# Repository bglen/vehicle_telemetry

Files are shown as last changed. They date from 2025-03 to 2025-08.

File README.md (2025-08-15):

# Vehicle Telemetry System

*Note: This is a work in progress and many features are not implemented yet.*

The Vehicle Telemetry System is an offline-first, containerized CAN data logging system. The system is designed to provide live telemetry and data logging for race cars, but can easilly be adapted to any mobile vehicle or robotic platform that uses CAN networks.

# Architecture Overview
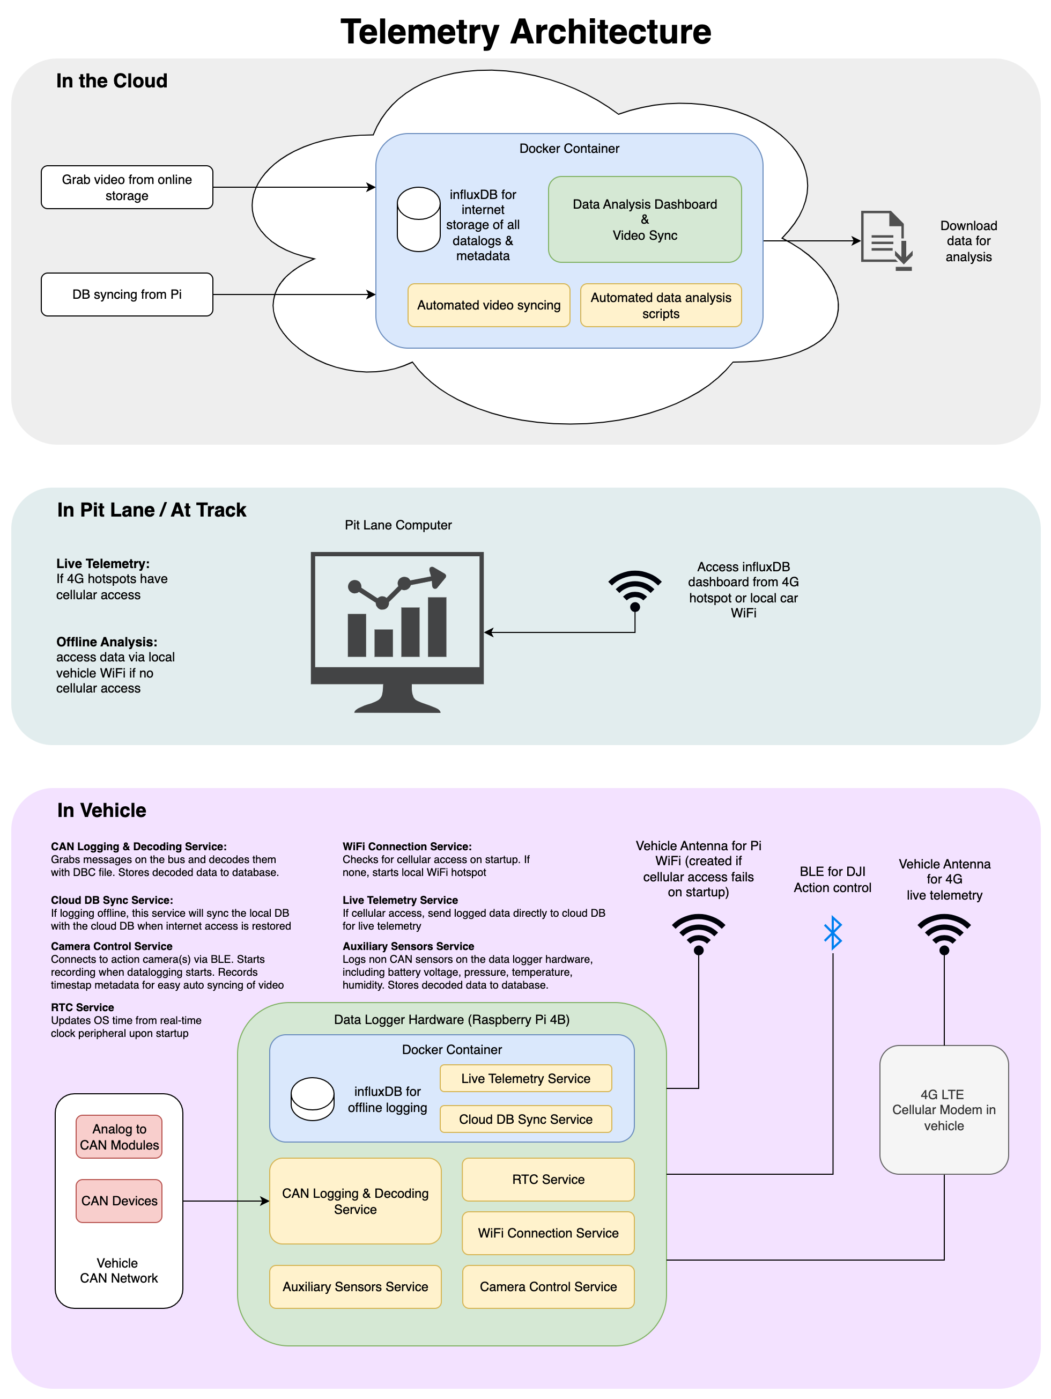
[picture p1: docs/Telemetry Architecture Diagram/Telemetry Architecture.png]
Telemetry Architecture


### Current Features
- Logs CAN and decodes to CSV file
- Ability to decode using multiple DBC files
- Access and download decoded log files on the logger's local WiFi hotspot
- Handles sudden power loss gracefully
- Supports two CAN 2.0B networks up to 1 Mbps
- Logs data from NMEA format USB GPS devices

### Future Functionality
- Stores data to local influxDB database when logging offline. Syncs data to cloud database when internet access is detected.
- Bluetooth control of action cameras (GoPro, DJI Action)

# Data Logger

## Hardware Overview

This repo contains the hardware design for an open-source Raspberry Pi-based CAN data logger.

- Raspberry Pi 4 Model B
- 12V nominal power
- Can log two CAN networks
- GPIO for remote button for log start/stop and logging status LEDs
- Real time clock for accurate data time-stamps when not connected to internet
- Temperature, pressure, and humidity SPI sensor
- Bus voltage logging

## Datalogger Software Setup

1. Create a fresh install of Raspberry Pi OS on your Pi 4B
2. Connect to your Pi via SSH or other methods. Ensure it has an internet connection.
3. Update apt and install git and jq: `sudo apt upgrade -y && sudo apt install -y git jq`
4. Clone the repo: `git clone https://github.com/bglen/vehicle_telemetry`
5. Go to the setup folder: `cd vehicle_telemetry/software/datalogger/setup`
6. Make **install.sh** executable: `chmod +x install.sh`
7. Run the installer: `./install.sh`
8. During the install, enter in your preferred access point network name and trusted network details.
9. Reboot the Pi: `sudo reboot`

# Data Visualiation Tool

A python data visualization tool is provided and uses **rerun.io** to visualize .CSV log files.

## License
MIT License

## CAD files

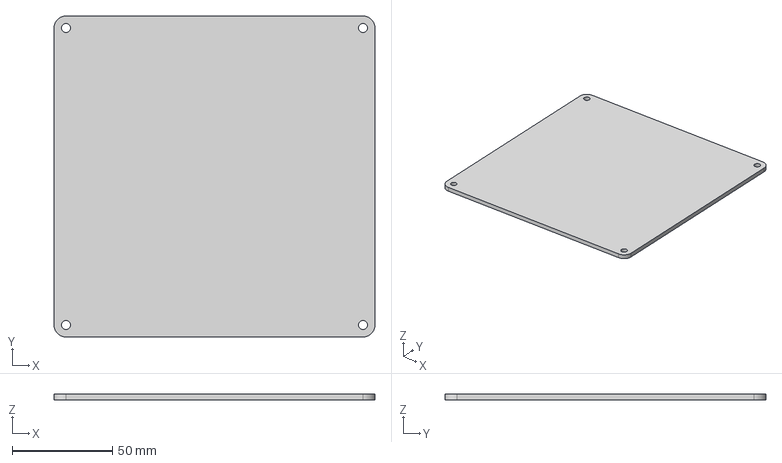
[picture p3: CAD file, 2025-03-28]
hardware/cad/step/datalogger_lid.step
160.0 x 160.0 x 3.00 mm

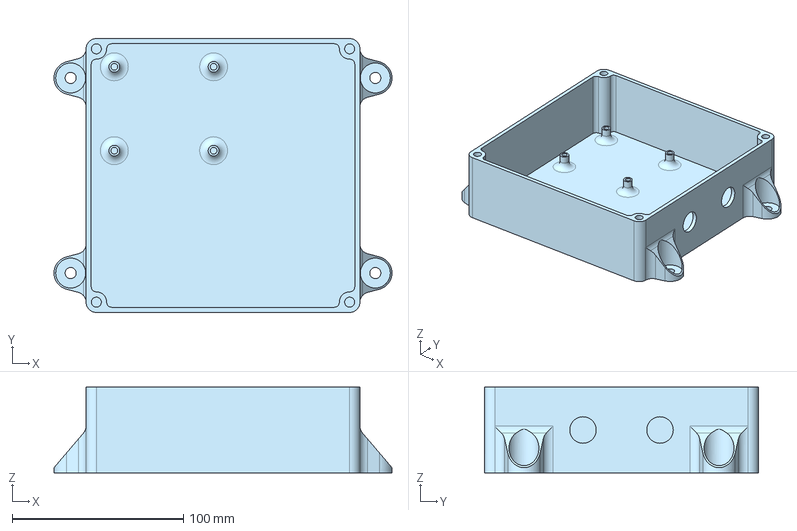
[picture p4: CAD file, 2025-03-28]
hardware/cad/step/datalogger_enclosure.step
197.5 x 160.0 x 50.0 mm

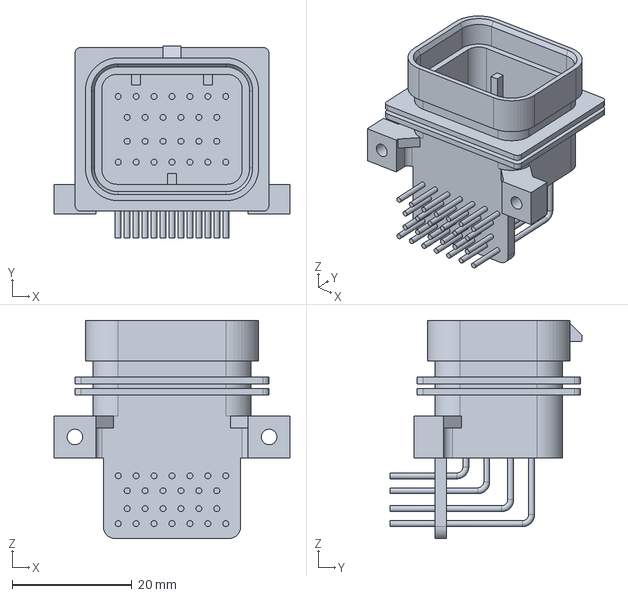
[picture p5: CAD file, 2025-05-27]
hardware/can_datalogger_board/3d_models/amp_superseal_9-6437287-8.step
39.5 x 32.1 x 36.5 mm

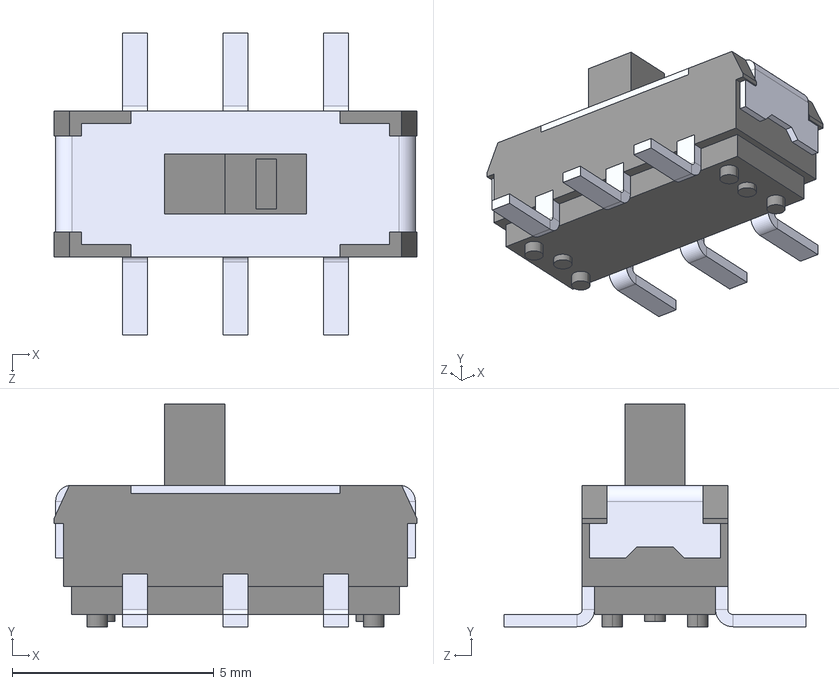
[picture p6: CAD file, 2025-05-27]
hardware/can_datalogger_board/3d_models/JS202011SCQN.STEP
8.99 x 5.51 x 7.49 mm

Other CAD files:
hardware/cad/stl/datalogger_enclosure.stl
hardware/cad/stl/datalogger_lid.stl

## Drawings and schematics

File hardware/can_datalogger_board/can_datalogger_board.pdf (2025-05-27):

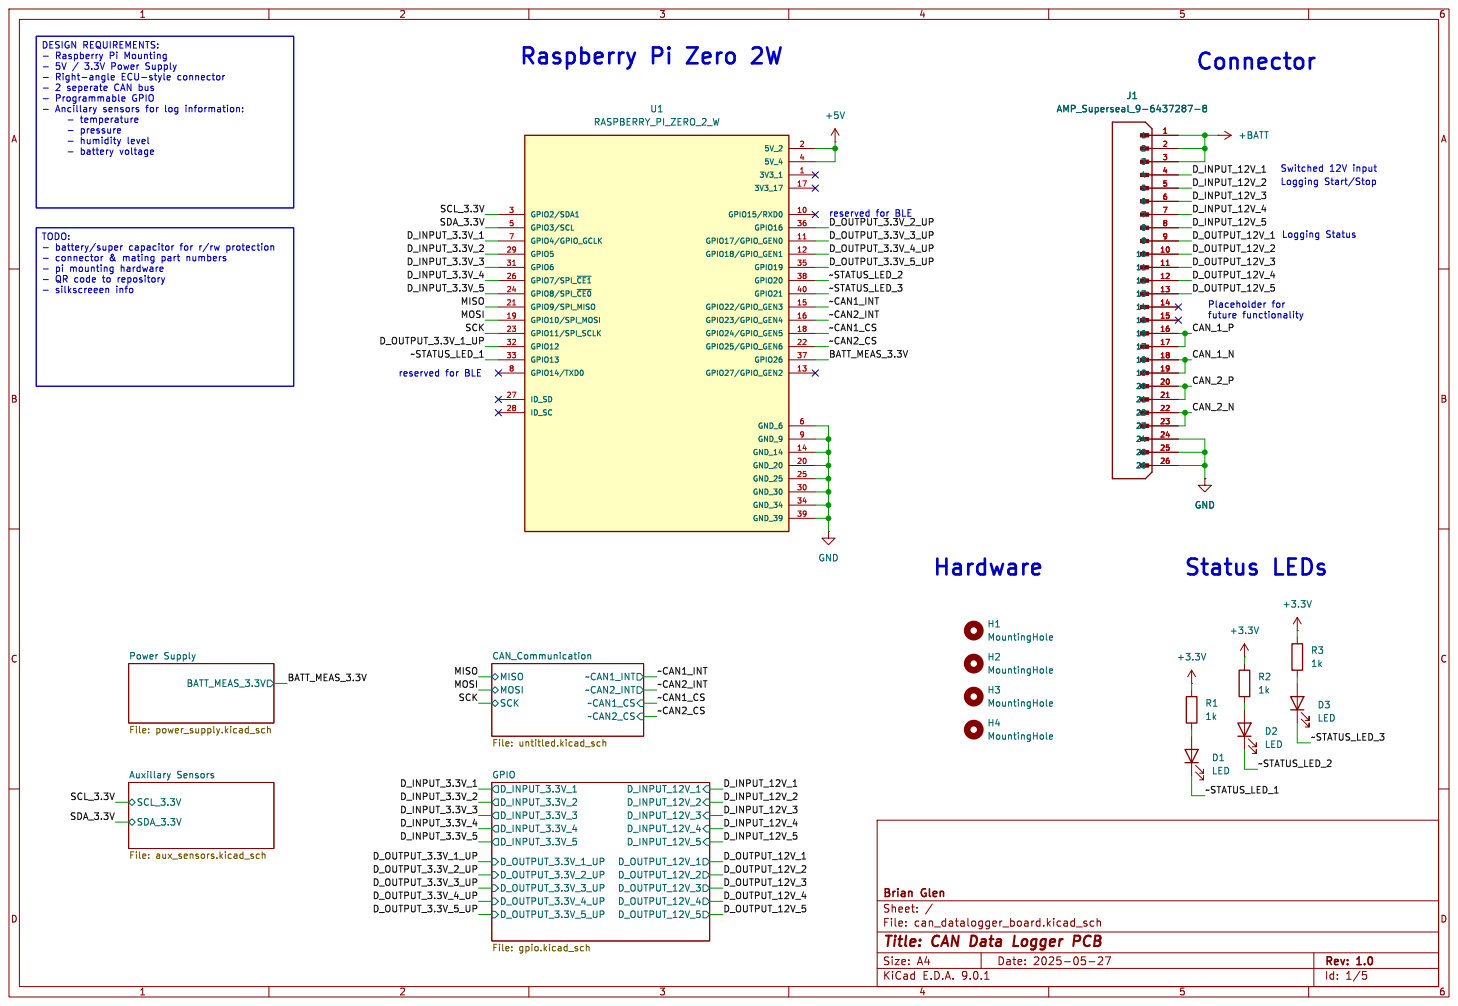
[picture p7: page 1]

Switched 12V input reserved for BLE

- QR code to repository

File: can_datalogger_board.kicad_sch Sheet: / Brian Glen

Id: 1/5 Title: CAN Data Logger PCB

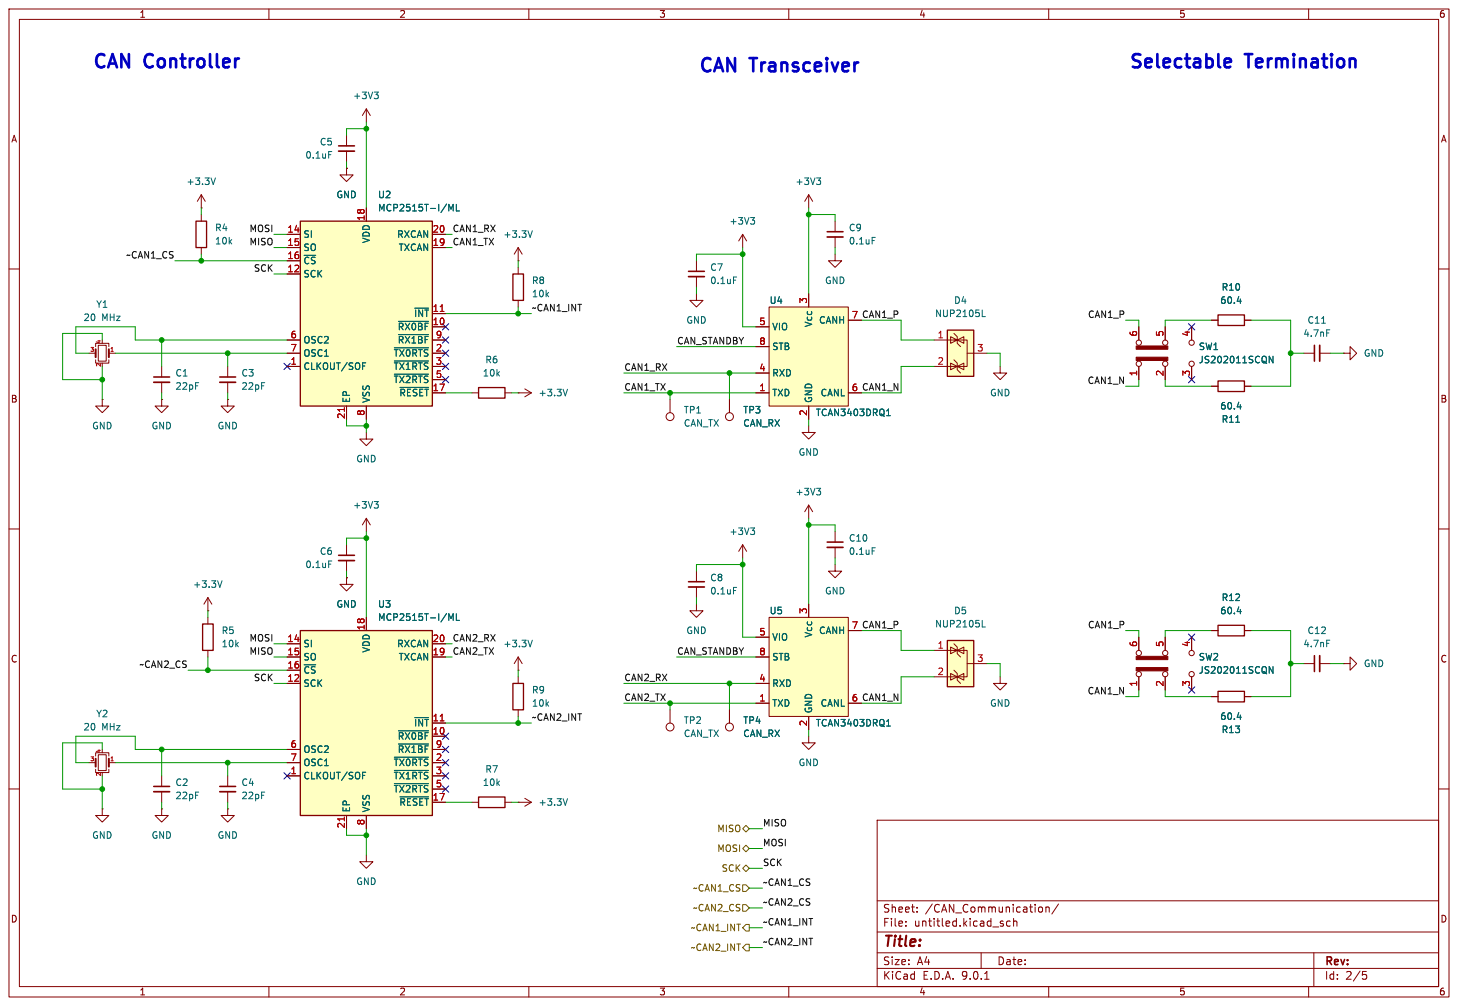
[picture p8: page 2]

8 RXCAN 20 TXCAN 19 ~{INT} 11 ~{RX0BF}10 ~{RX1BF}9 ~{TX0RTS}2 ~{TX1RTS}3 ~{TX2RTS}5 ~{RESET} 17 GND

8 RXCAN 20 TXCAN 19 ~{INT} 11 ~{RX0BF}10 ~{RX1BF}9 ~{TX0RTS}2 ~{TX1RTS}3 ~{TX2RTS}5 ~{RESET} 17 U2 MCP2515T-I/ML +3V3 R9

JS202011SCQN GND MISO MOSI SCK

8 RXCAN 20 TXCAN 19 ~{INT} 11 ~{RX0BF}10 ~{RX1BF}9 ~{TX0RTS}2 ~{TX1RTS}3 ~{TX2RTS}5 ~{RESET} 17 U3 MCP2515T-I/ML GND

Id: 2/5 Title: File: untitled.kicad_sch Sheet: /CAN_Communication/ GND GND

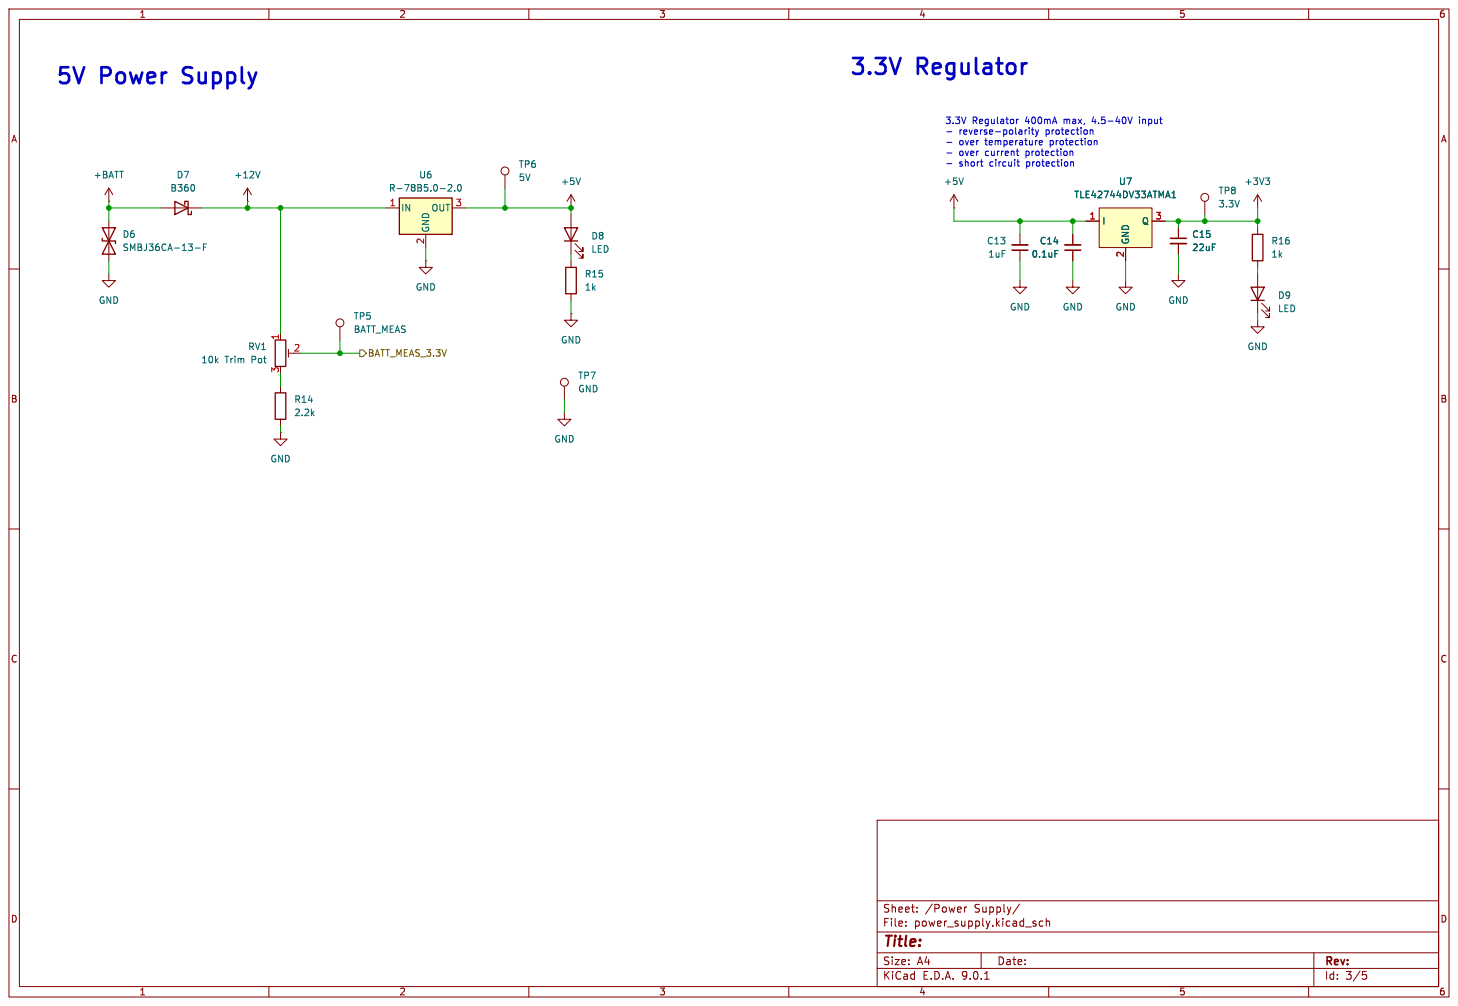
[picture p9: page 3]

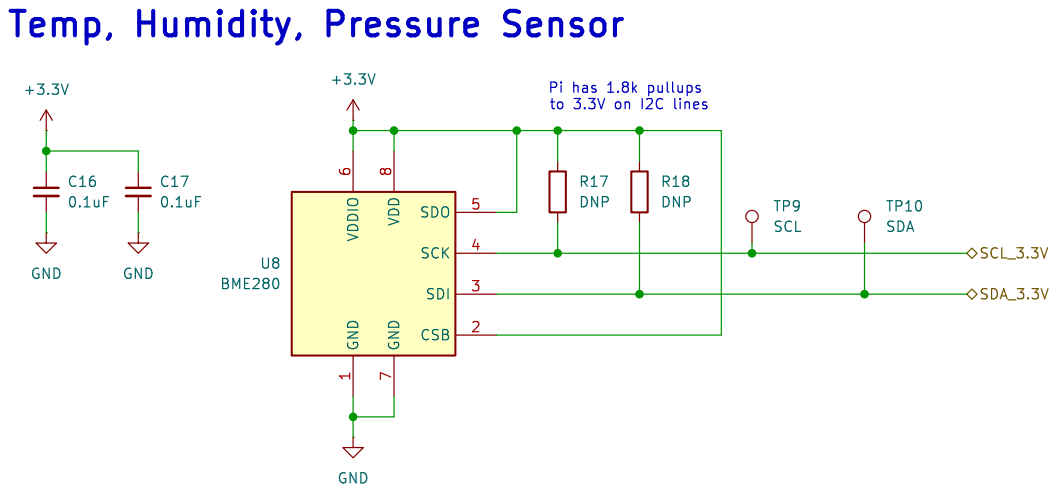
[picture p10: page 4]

7 SDO 5 SCK 4 SDI 3 CSB 2 U8 BME280 GND

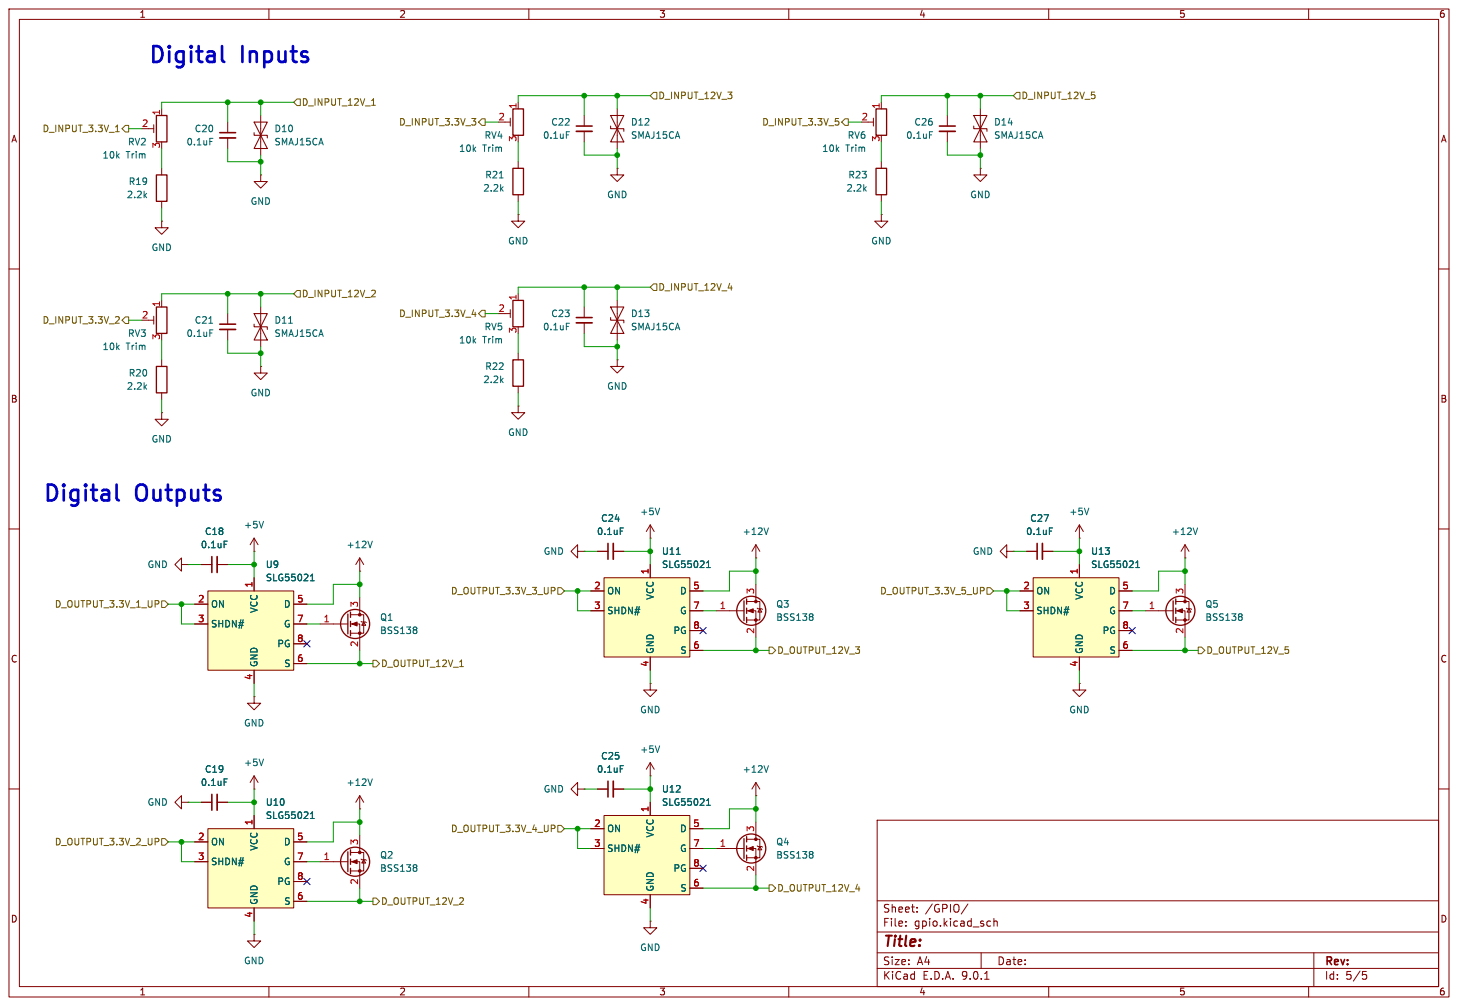
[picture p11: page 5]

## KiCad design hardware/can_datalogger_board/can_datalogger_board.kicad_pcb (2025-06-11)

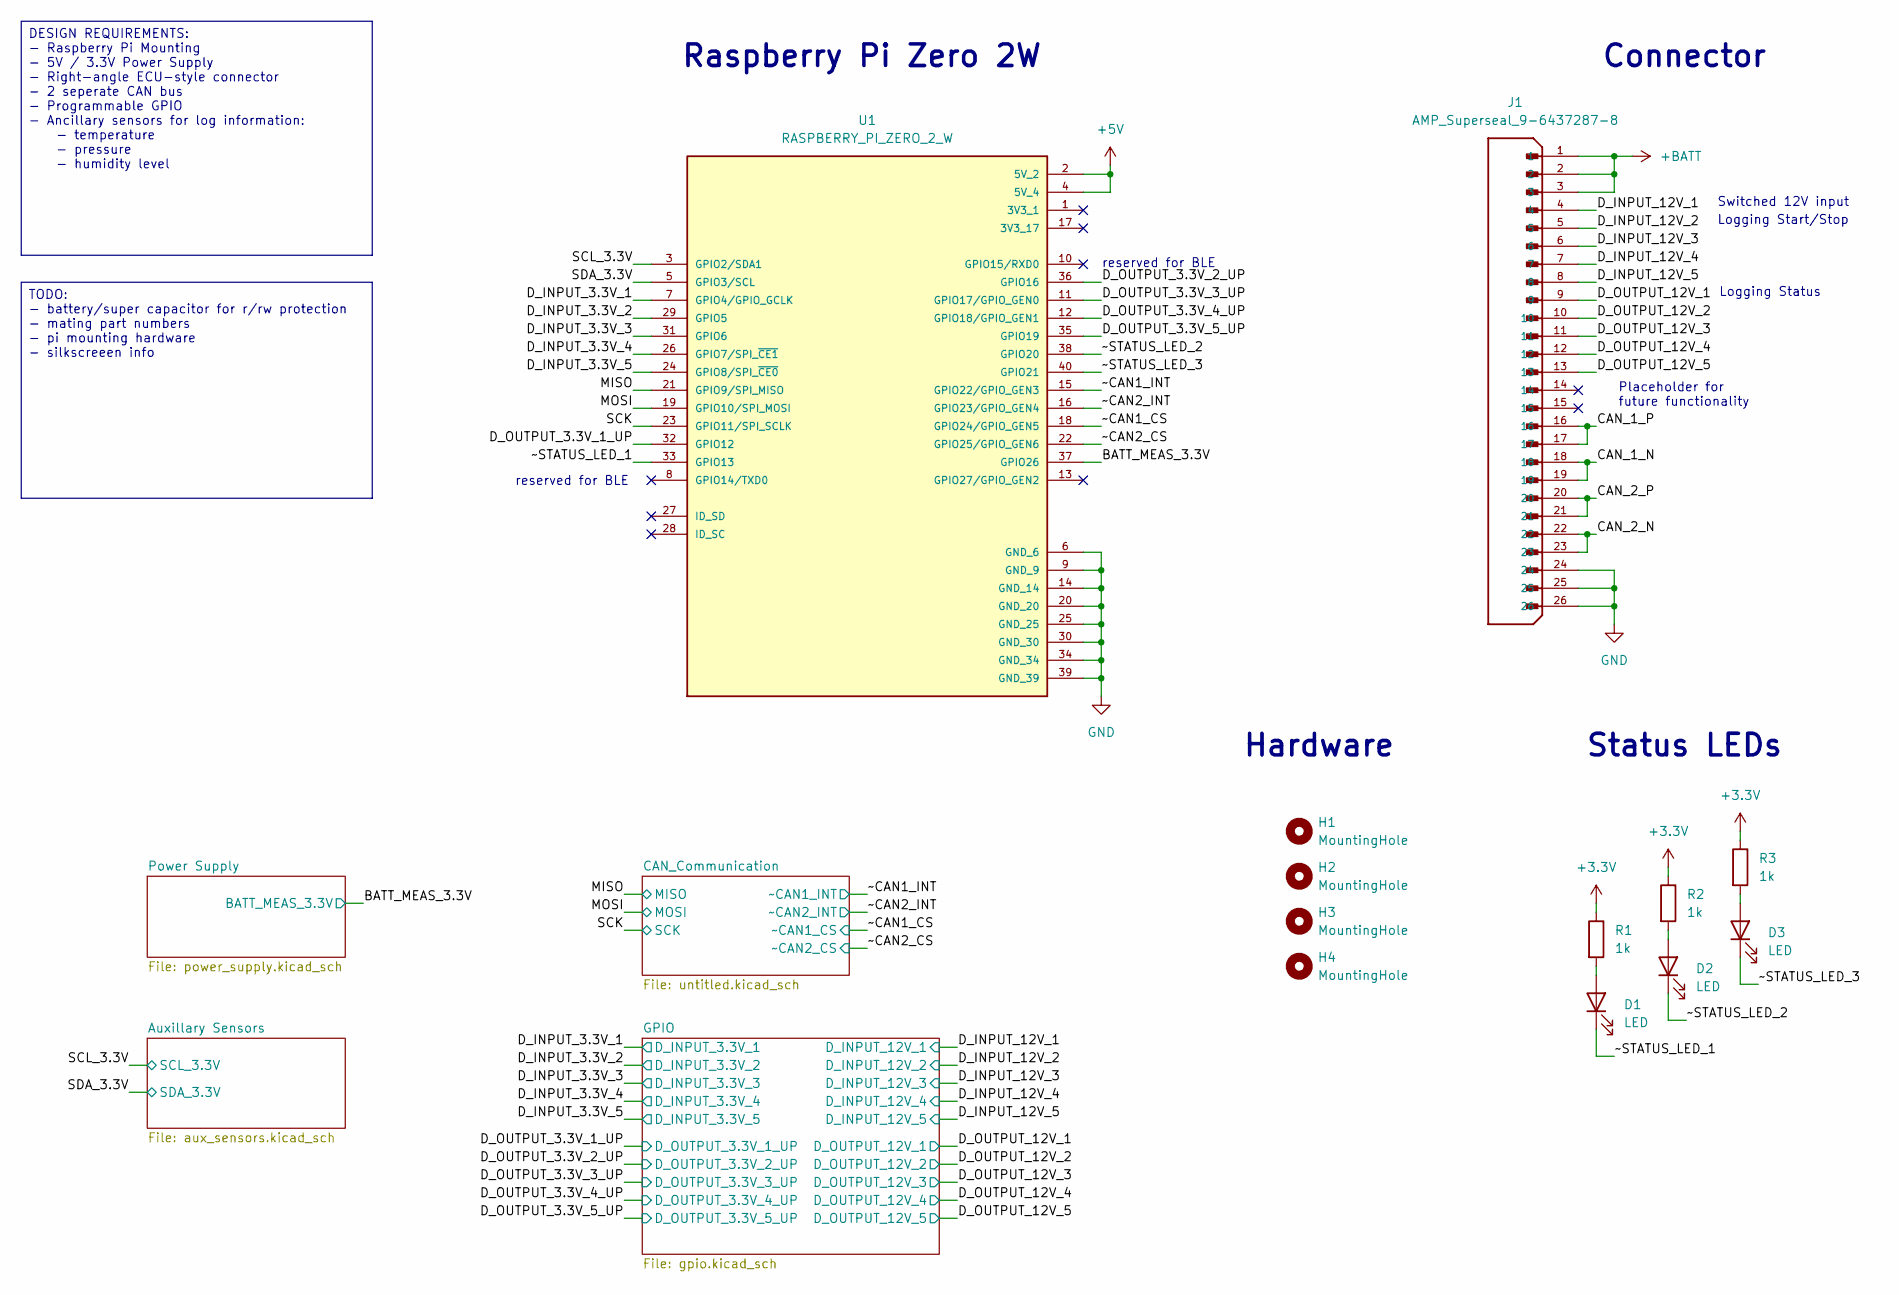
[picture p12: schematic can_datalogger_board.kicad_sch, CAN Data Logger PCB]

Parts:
D1, D2, D3: LED; LED_0603_1608Metric
H1, H2, H3, H4: MountingHole; MountingHole_3.2mm_M3
J1: AMP_Superseal_9-6437287-8; TE_9-6437287-8; PARTREV A1
R1, R2, R3: 1k; R_0603_1608Metric
U1: RASPBERRY_PI_ZERO_2_W; MODULE_RASPBERRY_PI_ZERO_2_W; PARTREV April 2024

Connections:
+3.3V: R1.1, R2.1, R3.1; also elsewhere on the board
+5V: U1.2 (5V_2), U1.4 (5V_4); also elsewhere on the board
+BATT: J1.1, J1.2, J1.3; also elsewhere on the board
/BATT_MEAS_3.3V: U1.37 (GPIO26)
/CAN_1_N: J1.18, J1.19
/CAN_1_P: J1.16, J1.17
/CAN_2_N: J1.22, J1.23
/CAN_2_P: J1.20, J1.21
/D_INPUT_3.3V_1: U1.7 (GPIO4/GPIO_GCLK); also elsewhere on the board
/D_INPUT_3.3V_2: U1.29 (GPIO5); also elsewhere on the board
/D_INPUT_3.3V_3: U1.31 (GPIO6); also elsewhere on the board
/D_INPUT_3.3V_4: U1.26 (GPIO7/SPI_~CE1); also elsewhere on the board
/D_INPUT_3.3V_5: U1.24 (GPIO8/SPI_~CE0); also elsewhere on the board
/D_INPUT_12V_1: J1.4; also elsewhere on the board
/D_INPUT_12V_2: J1.5; also elsewhere on the board
/D_INPUT_12V_3: J1.6; also elsewhere on the board
/D_INPUT_12V_4: J1.7; also elsewhere on the board
/D_INPUT_12V_5: J1.8; also elsewhere on the board
/D_OUTPUT_3.3V_1_UP: U1.32 (GPIO12); also elsewhere on the board
/D_OUTPUT_3.3V_2_UP: U1.36 (GPIO16); also elsewhere on the board
/D_OUTPUT_3.3V_3_UP: U1.11 (GPIO17/GPIO_GEN0); also elsewhere on the board
/D_OUTPUT_3.3V_4_UP: U1.12 (GPIO18/GPIO_GEN1); also elsewhere on the board
/D_OUTPUT_3.3V_5_UP: U1.35 (GPIO19); also elsewhere on the board
/D_OUTPUT_12V_1: J1.9; also elsewhere on the board
/D_OUTPUT_12V_2: J1.10; also elsewhere on the board
/D_OUTPUT_12V_3: J1.11; also elsewhere on the board
/D_OUTPUT_12V_4: J1.12; also elsewhere on the board
/D_OUTPUT_12V_5: J1.13; also elsewhere on the board
/MISO: U1.21 (GPIO9/SPI_MISO); also elsewhere on the board
/MOSI: U1.19 (GPIO10/SPI_MOSI); also elsewhere on the board
/SCK: U1.23 (GPIO11/SPI_SCLK); also elsewhere on the board
/SCL_3.3V: U1.3 (GPIO2/SDA1); also elsewhere on the board
/SDA_3.3V: U1.5 (GPIO3/SCL); also elsewhere on the board
/~CAN1_CS: U1.18 (GPIO24/GPIO_GEN5); also elsewhere on the board
/~CAN1_INT: U1.15 (GPIO22/GPIO_GEN3); also elsewhere on the board
/~CAN2_CS: U1.22 (GPIO25/GPIO_GEN6); also elsewhere on the board
/~CAN2_INT: U1.16 (GPIO23/GPIO_GEN4); also elsewhere on the board
/~STATUS_LED_1: D1.1 (K), U1.33 (GPIO13)
/~STATUS_LED_2: D2.1 (K), U1.38 (GPIO20)
/~STATUS_LED_3: D3.1 (K), U1.40 (GPIO21)
GND: J1.24, J1.25, J1.26, U1.6 (GND_6), U1.9 (GND_9), U1.14 (GND_14), U1.20 (GND_20), U1.25 (GND_25), U1.30 (GND_30), U1.34 (GND_34), U1.39 (GND_39); also elsewhere on the board
unnamed: D1.2 (A), R1.2
unnamed: D2.2 (A), R2.2
unnamed: D3.2 (A), R3.2

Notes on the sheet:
Switched 12V input
reserved for BLE
Status LEDs
Logging Start/Stop
Logging Status
Connector
Hardware
Raspberry Pi Zero 2W
Placeholder for future functionality
TODO: - battery/super capacitor for r/rw protection - mating part numbers - pi mounting hardware - silkscreeen info
DESIGN REQUIREMENTS: - Raspberry Pi Mounting - 5V / 3.3V Power Supply - Right-angle ECU-style connector - 2 seperate CAN bus - Programmable GPIO - Ancillary sensors for log information: - temperature - pressure - humidity level

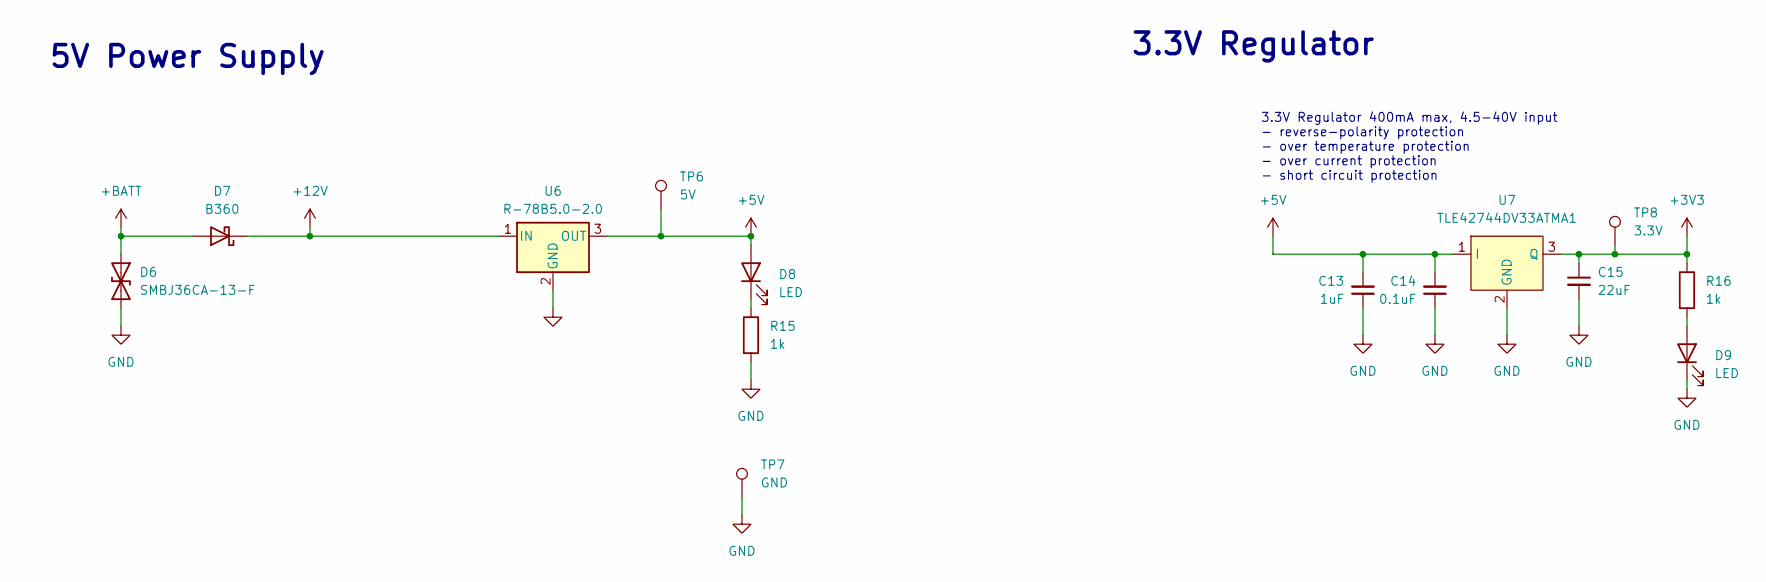
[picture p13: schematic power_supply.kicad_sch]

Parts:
C13: 1uF; C_0603_1608Metric
C14: 0.1uF; C_0603_1608Metric
C15: 22uF; C_0805_2012Metric
D6: SMBJ36CA-13-F; D_SMB
D7: B360; D_SMC
D8, D9: LED; LED_0603_1608Metric
R15, R16: 1k; R_0603_1608Metric
TP6: 5V; TestPoint_Pad_D1.0mm
TP7: GND; TestPoint_Pad_D1.0mm
TP8: 3.3V; TestPoint_Pad_D1.0mm
U6: R-78B5.0-2.0; Converter_DCDC_RECOM_R-78B-2.0_THT
U7: TLE42744DV33ATMA1; TO-252-3_TabPin2

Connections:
+3V3: C15.1, R16.1, TP8.1, U7.3 (Q); also elsewhere on the board
+5V: C13.2, C14.2, D8.2 (A), TP6.1, U6.3 (OUT), U7.1 (I); also elsewhere on the board
+12V: D7.1 (K), U6.1 (IN); also elsewhere on the board
+BATT: D6.1 (A1), D7.2 (A); also elsewhere on the board
GND: C13.1, C14.1, C15.2, D6.2 (A2), D9.1 (K), R15.2, TP7.1, U6.2 (GND), U7.2 (GND); also elsewhere on the board
unnamed: D8.1 (K), R15.1
unnamed: D9.2 (A), R16.2

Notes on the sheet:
3.3V Regulator
3.3V Regulator 400mA max, 4.5-40V input - reverse-polarity protection - over temperature protection - over current protection - short circuit protection
5V Power Supply

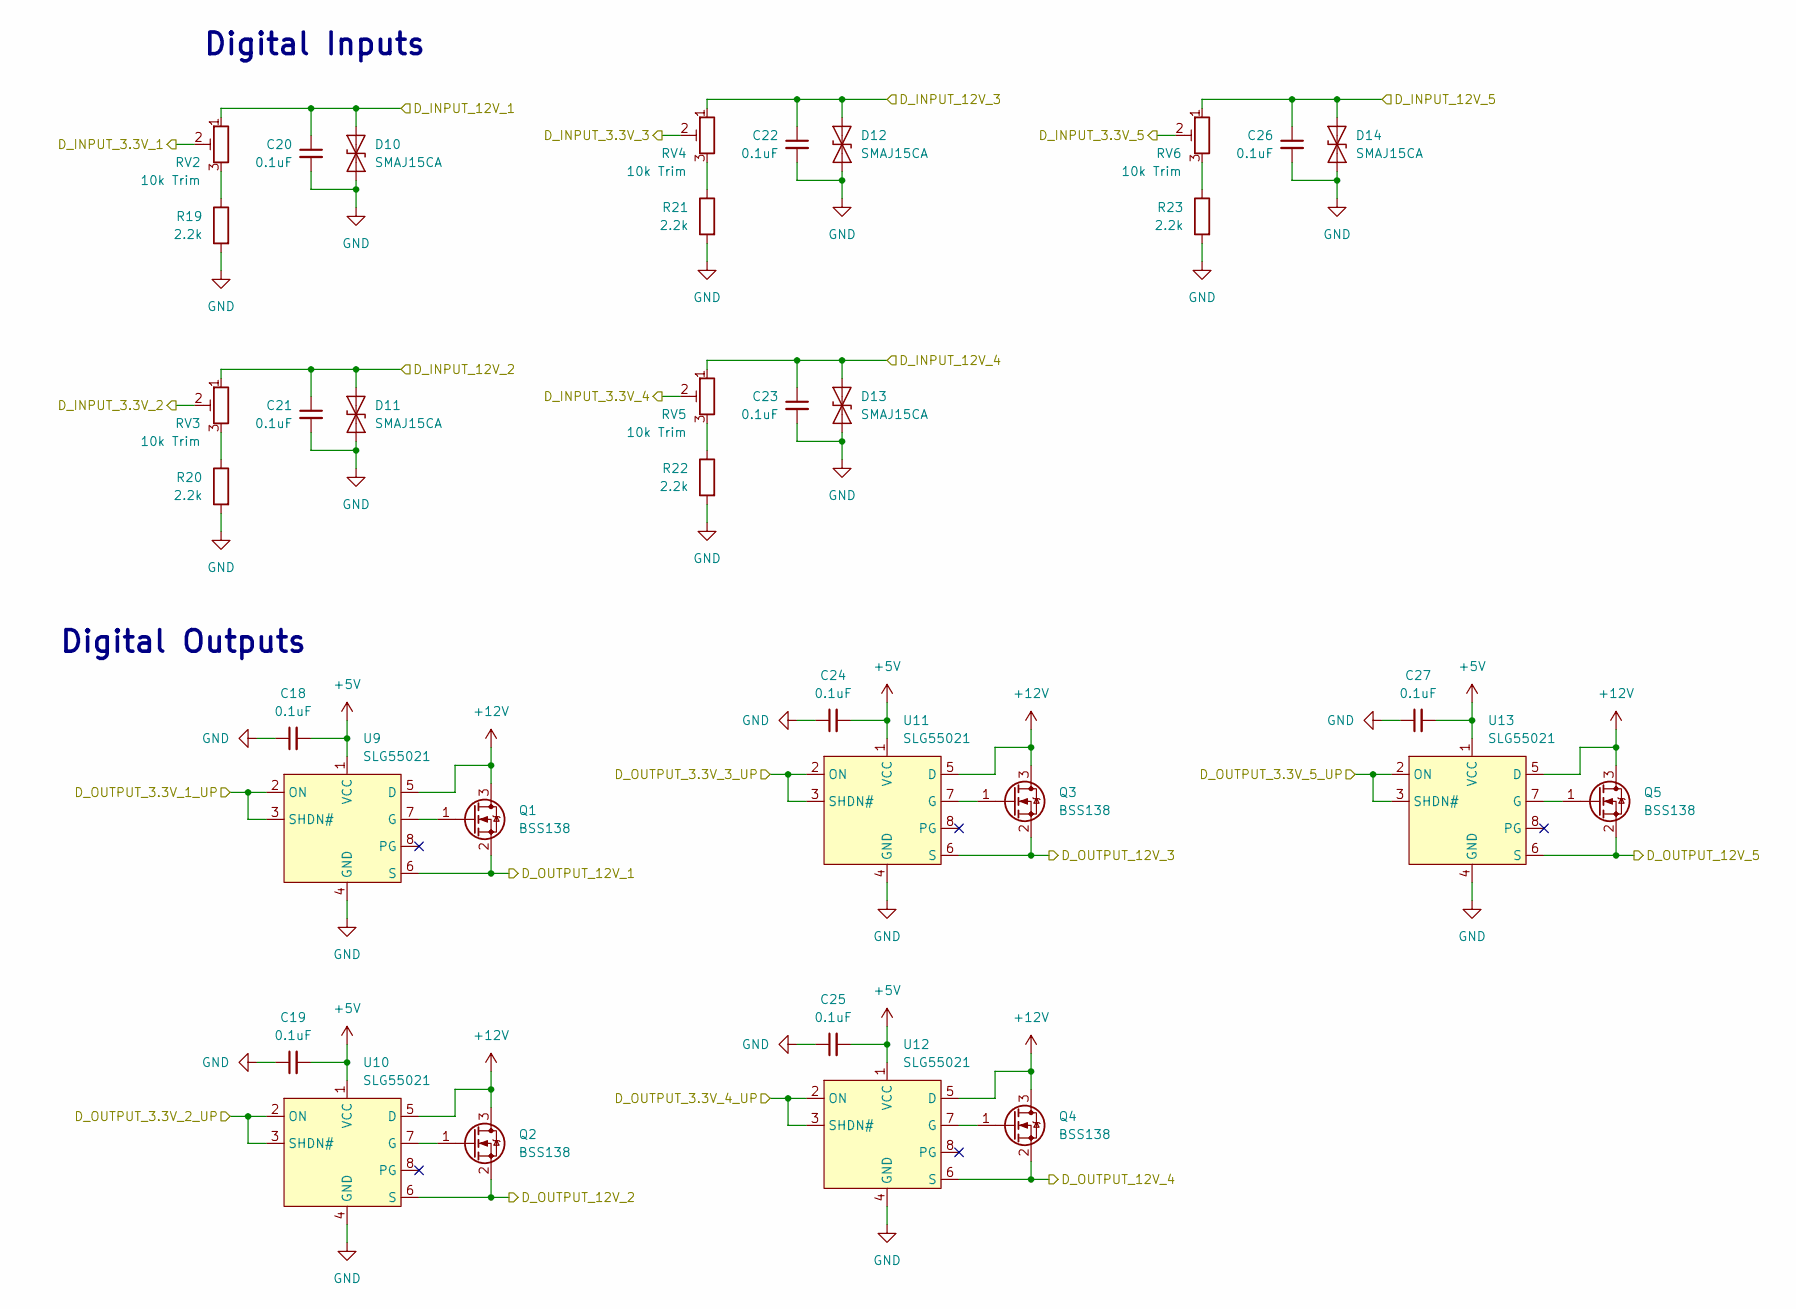
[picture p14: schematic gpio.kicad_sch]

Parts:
C18, C19, C20, C21, C22, C23, C24, C25, C26, C27: 0.1uF; C_0603_1608Metric
D10, D11, D12, D13, D14: SMAJ15CA; D_SMA
Q1, Q2, Q3, Q4, Q5: BSS138; SOT-23
R19, R20, R21, R22, R23: 2.2k; R_0603_1608Metric
RV2, RV3, RV4, RV5, RV6: 10k Trim; Potentiometer_Bourns_TC33X_Vertical
U9, U10, U11, U12, U13: SLG55021; TDFN-8-1EP_2x2mm_P0.5mm_EP0.8x1.2mm

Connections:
+5V: C18.2, C19.2, C24.2, C25.2, C27.2, U9.1 (VCC), U10.1 (VCC), U11.1 (VCC), U12.1 (VCC), U13.1 (VCC); also elsewhere on the board
+12V: Q1.3 (D), Q2.3 (D), Q3.3 (D), Q4.3 (D), Q5.3 (D), U9.5 (D), U10.5 (D), U11.5 (D), U12.5 (D), U13.5 (D); also elsewhere on the board
/D_INPUT_3.3V_1: RV2.2; also elsewhere on the board
/D_INPUT_3.3V_2: RV3.2; also elsewhere on the board
/D_INPUT_3.3V_3: RV4.2; also elsewhere on the board
/D_INPUT_3.3V_4: RV5.2; also elsewhere on the board
/D_INPUT_3.3V_5: RV6.2; also elsewhere on the board
/D_INPUT_12V_1: C20.1, D10.1 (A1), RV2.1; also elsewhere on the board
/D_INPUT_12V_2: C21.1, D11.1 (A1), RV3.1; also elsewhere on the board
/D_INPUT_12V_3: C22.1, D12.1 (A1), RV4.1; also elsewhere on the board
/D_INPUT_12V_4: C23.1, D13.1 (A1), RV5.1; also elsewhere on the board
/D_INPUT_12V_5: C26.1, D14.1 (A1), RV6.1; also elsewhere on the board
/D_OUTPUT_3.3V_1_UP: U9.2 (ON), U9.3 (SHDN#); also elsewhere on the board
/D_OUTPUT_3.3V_2_UP: U10.2 (ON), U10.3 (SHDN#); also elsewhere on the board
/D_OUTPUT_3.3V_3_UP: U11.2 (ON), U11.3 (SHDN#); also elsewhere on the board
/D_OUTPUT_3.3V_4_UP: U12.2 (ON), U12.3 (SHDN#); also elsewhere on the board
/D_OUTPUT_3.3V_5_UP: U13.2 (ON), U13.3 (SHDN#); also elsewhere on the board
/D_OUTPUT_12V_1: Q1.2 (S), U9.6 (S); also elsewhere on the board
/D_OUTPUT_12V_2: Q2.2 (S), U10.6 (S); also elsewhere on the board
/D_OUTPUT_12V_3: Q3.2 (S), U11.6 (S); also elsewhere on the board
/D_OUTPUT_12V_4: Q4.2 (S), U12.6 (S); also elsewhere on the board
/D_OUTPUT_12V_5: Q5.2 (S), U13.6 (S); also elsewhere on the board
GND: C18.1, C19.1, C20.2, C21.2, C22.2, C23.2, C24.1, C25.1, C26.2, C27.1, D10.2 (A2), D11.2 (A2), D12.2 (A2), D13.2 (A2), D14.2 (A2), R19.2, R20.2, R21.2, R22.2, R23.2, U9.4 (GND), U10.4 (GND), U11.4 (GND), U12.4 (GND), U13.4 (GND); also elsewhere on the board
unnamed: Q1.1 (G), U9.7 (G)
unnamed: Q2.1 (G), U10.7 (G)
unnamed: Q3.1 (G), U11.7 (G)
unnamed: Q4.1 (G), U12.7 (G)
unnamed: Q5.1 (G), U13.7 (G)
unnamed: R19.1, RV2.3
unnamed: R20.1, RV3.3
unnamed: R21.1, RV4.3
unnamed: R22.1, RV5.3
unnamed: R23.1, RV6.3

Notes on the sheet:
Digital Outputs
Digital Inputs

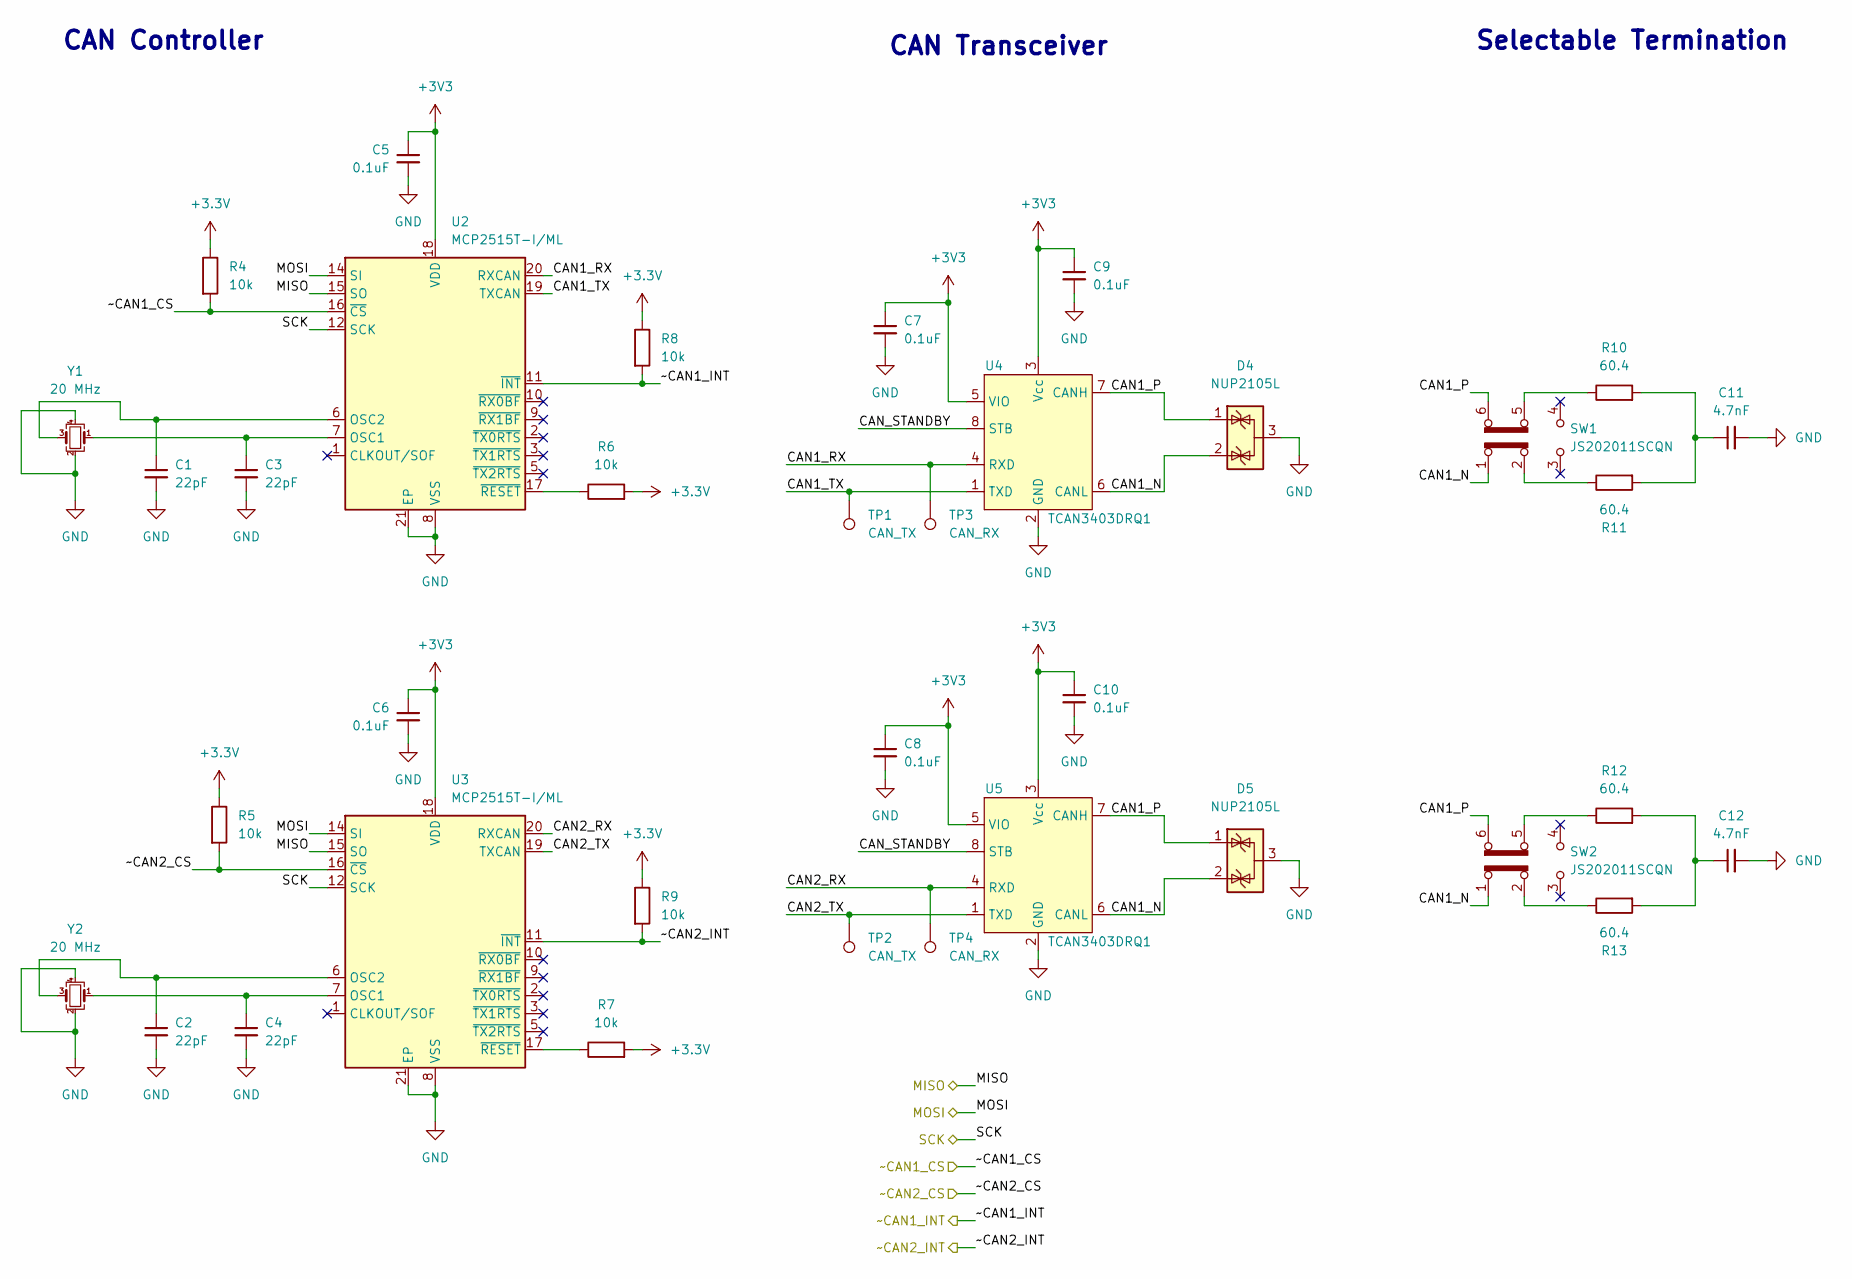
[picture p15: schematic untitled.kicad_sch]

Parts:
C1, C2, C3, C4: 22pF; C_0603_1608Metric
C5, C6, C7, C8, C9, C10: 0.1uF; C_0603_1608Metric
C11, C12: 4.7nF; C_0603_1608Metric
D4, D5: NUP2105L; SOT-23
R4, R5, R6, R7, R8, R9: 10k; R_0603_1608Metric
R10, R11, R12, R13: 60.4; R_0603_1608Metric
SW1, SW2: JS202011SCQN; SW_JS202011SCQN
TP1, TP2: CAN_TX; TestPoint_Pad_D1.0mm
TP3, TP4: CAN_RX; TestPoint_Pad_D1.0mm
U2, U3: MCP2515T-I/ML; QFN-20-1EP_4x4mm_P0.5mm_EP2.5x2.5mm
U4, U5: TCAN3403DRQ1; SOIC-8_3.9x4.9mm_P1.27mm
Y1, Y2: 20 MHz; Crystal_SMD_2520-4Pin_2.5x2.0mm

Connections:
+3.3V: R4.1, R5.1, R6.2, R7.2, R8.1, R9.1; also elsewhere on the board
+3V3: C5.1, C6.1, C7.1, C8.1, C9.1, C10.1, U2.18 (VDD), U3.18 (VDD), U4.3 (Vcc), U4.5 (VIO), U5.3 (Vcc), U5.5 (VIO); also elsewhere on the board
/CAN_Communication/CAN1_N: D4.2 (K), D5.2 (K), SW1.1 (A), SW2.1 (A), U4.6 (CANL), U5.6 (CANL)
/CAN_Communication/CAN1_P: D4.1 (K), D5.1 (K), SW1.6 (C), SW2.6 (C), U4.7 (CANH), U5.7 (CANH)
/CAN_Communication/CAN1_RX: TP3.1, U2.20 (RXCAN), U4.4 (RXD)
/CAN_Communication/CAN1_TX: TP1.1, U2.19 (TXCAN), U4.1 (TXD)
/CAN_Communication/CAN2_RX: TP4.1, U3.20 (RXCAN), U5.4 (RXD)
/CAN_Communication/CAN2_TX: TP2.1, U3.19 (TXCAN), U5.1 (TXD)
/CAN_Communication/CAN_STANDBY: U4.8 (STB), U5.8 (STB)
/MISO: U2.15 (SO), U3.15 (SO); also elsewhere on the board
/MOSI: U2.14 (SI), U3.14 (SI); also elsewhere on the board
/SCK: U2.12 (SCK), U3.12 (SCK); also elsewhere on the board
/~CAN1_CS: R4.2, U2.16 (~CS); also elsewhere on the board
/~CAN1_INT: R8.2, U2.11 (~INT); also elsewhere on the board
/~CAN2_CS: R5.2, U3.16 (~CS); also elsewhere on the board
/~CAN2_INT: R9.2, U3.11 (~INT); also elsewhere on the board
GND: C1.2, C2.2, C3.2, C4.2, C5.2, C6.2, C7.2, C8.2, C9.2, C10.2, C11.2, C12.2, D4.3 (A), D5.3 (A), U2.8 (VSS), U2.21 (EP), U3.8 (VSS), U3.21 (EP), U4.2 (GND), U5.2 (GND), Y1.2, Y1.4, Y2.2, Y2.4; also elsewhere on the board
unnamed: C11.1, R10.2, R11.2
unnamed: C12.1, R12.2, R13.2
unnamed: R10.1, SW1.5 (B)
unnamed: R11.1, SW1.2 (B)
unnamed: R12.1, SW2.5 (B)
unnamed: R13.1, SW2.2 (B)
unnamed: C3.1, U2.7 (OSC1), Y1.1
unnamed: C1.1, U2.6 (OSC2), Y1.3
unnamed: R6.1, U2.17 (~RESET)
unnamed: C4.1, U3.7 (OSC1), Y2.1
unnamed: C2.1, U3.6 (OSC2), Y2.3
unnamed: R7.1, U3.17 (~RESET)

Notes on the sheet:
Selectable Termination
CAN Transceiver
CAN Controller

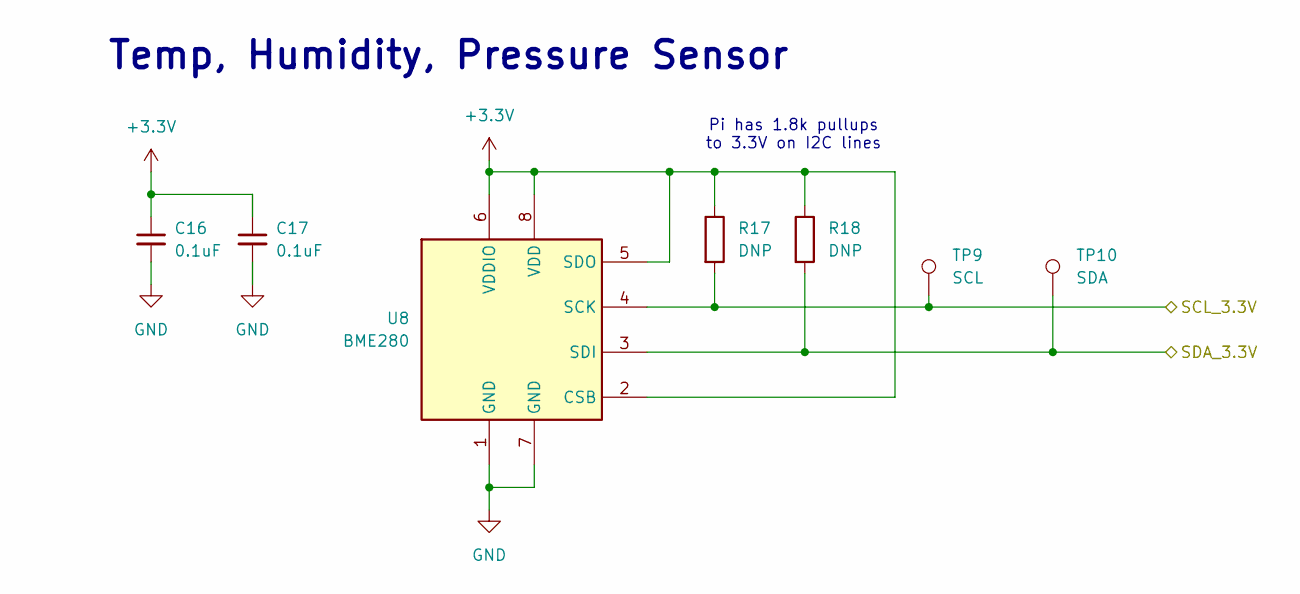
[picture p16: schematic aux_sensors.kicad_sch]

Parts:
C16, C17: 0.1uF; C_0603_1608Metric
R17, R18: DNP; R_0603_1608Metric
TP9: SCL; TestPoint_Pad_D1.0mm
TP10: SDA; TestPoint_Pad_D1.0mm
U8: BME280; Bosch_LGA-8_2.5x2.5mm_P0.65mm_ClockwisePinNumbering

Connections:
+3.3V: C16.1, C17.1, R17.1, R18.1, U8.2 (CSB), U8.5 (SDO), U8.6 (VDDIO), U8.8 (VDD); also elsewhere on the board
/SCL_3.3V: R17.2, TP9.1, U8.4 (SCK); also elsewhere on the board
/SDA_3.3V: R18.2, TP10.1, U8.3 (SDI); also elsewhere on the board
GND: C16.2, C17.2, U8.1 (GND), U8.7 (GND); also elsewhere on the board

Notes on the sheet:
Pi has 1.8k pullups to 3.3V on I2C lines
Temp, Humidity, Pressure Sensor

Board: 2 copper layers, 104 parts (1 on the bottom side), 76 nets, no tracks yet.

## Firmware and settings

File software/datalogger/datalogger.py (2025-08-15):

import os
import csv
import time
import threading
import sys
import select
import termios
import tty
from datetime import datetime
from gpiozero import LED, Button

# Python modules
import canbus
import gps

# === VK-162 GPS ===
USE_GPS = True          # Set to False to disable GPS logging

# === GPIO ===
button = Button(6, pull_up = True, bounce_time = 0.05)
led = LED(5, initial_value=False)
led.off()

# === Logging === 
OUTPUT_DIR = os.path.expanduser('~/logs')

# === Global Variables ===
logging_active = False
csvfile = None
csv_writer = None
start_time = None

def new_log_file():
    """
    Create a new CSV log file and write header.
    """
    global csvfile, csv_writer, start_time

    os.makedirs(OUTPUT_DIR, exist_ok=True) # make output directory if it does not exist
    timestamp_str = datetime.now().strftime('%Y-%m-%d_%I-%M-%S-%p')
    filename = os.path.join(OUTPUT_DIR, f'can_log_{timestamp_str}.csv')
    csvfile = open(filename, mode='w', newline='')
    csv_writer = csv.writer(csvfile)

    # With the DBC loaded we can build our header from all the message declarations
    header = ['Time (s)', 'Message ID'] + canbus.signal_columns
    if USE_GPS:
        header += gps.GPS_COLUMNS

    csv_writer.writerow(header)
    start_time = time.time()

def toggle_logging():
    """
    Start or stop logging when button is pressed.
    """
    global logging_active, csvfile

    if logging_active:
        print("Stopping logging...")
        logging_active = False
        led.off()
        if csvfile:
            csvfile.flush()
            csvfile.close()
            csvfile = None
    else:
        print("Starting new logging session...")
        new_log_file()
        logging_active = True
        led.on()

def log_loop():
    """
    Logging loop to receive CAN frames, decode, append GPS, write to CSV, repeat.
    """
    global logging_active

    # Enable CLI commands if script was started from the terminal
    input_enabled = sys.stdin.isatty()
    if input_enabled:
        old_settings = termios.tcgetattr(sys.stdin)
        tty.setcbreak(sys.stdin.fileno())

    try:
        while True:
            # Check for user input only when not logging
            if input_enabled and not logging_active and sys.stdin in select.select([sys.stdin], [], [], 0)[0]:
                if sys.stdin.readline().strip().lower() == "clear":
                    confirm_clear()

            # Skips calling recv (which is blocking) if not logging, allowing CLI commands
            if not logging_active:
                time.sleep(0.1)
                continue

            try:
                msg = canbus.can_interface.recv(timeout=1)
                if msg is None or not logging_active:
                    continue

                # Update the logging timestamp
                rel_time = time.time() - start_time

                # Try to decode the message with DBC
                vals = {col: '' for col in canbus.signal_columns}
                try:
                    decoded = canbus.db.decode_message(msg.arbitration_id, msg.data)
                    for name, val in decoded.items():
                        key = f"{canbus.db.get_message_by_frame_id(msg.arbitration_id).name}_{name}"
                        vals[key] = val
                except Exception:
                    vals['RAW_MSG'] = msg.data.hex()

                row = [f"{rel_time:.6f}", hex(msg.arbitration_id)]
                for col in canbus.signal_columns:
                    row.append(vals.get(col, ''))

                if USE_GPS:
                    row += [gps.gps_data['lat'], gps.gps_data['lon'], gps.gps_data['speed'], gps.gps_data['track']]

                csv_writer.writerow(row)
                csvfile.flush()

            except Exception as e:
                print(f"CAN receive error: {e}")
                led.off()
                time.sleep(1)
    finally:
        if input_enabled:
            termios.tcsetattr(sys.stdin, termios.TCSADRAIN, old_settings)

def confirm_clear():
    """
    Delete all existing CSV logs, if user confirms.
    """
    if logging_active:
        print("Cannot clear logs while logging is active.")
        return

    print("Are you sure you want to delete all .csv log files in can_logs? (Y/N): ", end="", flush=True)
    response = input().strip().lower()

    if response == 'y':
        deleted = 0
        for file in os.listdir(OUTPUT_DIR):
            if file.endswith('.csv'):
                file_path = os.path.join(OUTPUT_DIR, file)
                os.remove(file_path)
                deleted += 1
        print(f"{deleted} log file(s) deleted.")
    else:
        print("Clear canceled.")

def main():
    # Initialize CAN bus
    canbus.load_dbc()
    canbus.setup_interface()
    canbus.init()

    # Start GPS thread if enabled
    if USE_GPS:
        threading.Thread(target=gps.gps_reader, daemon=True).start()

    print("Ready. Press the button to start/stop logging.")
    button.when_pressed = toggle_logging

    try:
        log_loop()
    except KeyboardInterrupt:
        print("Shutting down.")
    finally:
        if csvfile:
            csvfile.flush()
            csvfile.close()
        canbus.bring_down_interface()

if __name__ == '__main__':
    main()

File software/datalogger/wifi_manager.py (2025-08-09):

#!/usr/bin/env python3

import json
import subprocess
from pathlib import Path

# Auto-detect repo dir (wifi_manager.py is in software/datalogger)
REPO_DIR = Path(__file__).resolve().parent
NETWORK_SETUP_FILE = REPO_DIR / "setup" / "network_setup.json"
AP_CONN_NAME = "vehicle-telemetry-ap"  # connection profile name for NM hotspot

def scan_ssids():
    """
    Scan for nearby Wi-Fi SSIDs.
    """
    result = subprocess.run(["iwlist", "wlan0", "scan"], stdout=subprocess.PIPE)
    ssids = []
    for line in result.stdout.decode().split("\n"):
        line = line.strip()
        if line.startswith("ESSID:"):
            ssid = line.split(":")[1].strip('"')
            if ssid:
                ssids.append(ssid)
    return ssids

def load_config():
    """
    Load full JSON config (AP + trusted networks).
    """
    with open(NETWORK_SETUP_FILE) as f:
        return json.load(f)

def configure_wifi_client(ssid, psk=None):
    """
    Configure for client-mode wifi connection.
    """
    # Make sure NM is running for client mode
    subprocess.run(["systemctl", "start", "NetworkManager"])
    # Delete any stale connection with same SSID (idempotent)
    subprocess.run(["nmcli", "connection", "delete", ssid], stdout=subprocess.DEVNULL, stderr=subprocess.DEVNULL)
    # Connect (no password if open)
    if psk:
        subprocess.run(["nmcli", "device", "wifi", "connect", ssid, "password", psk, "ifname", "wlan0"], check=False)
    else:
        subprocess.run(["nmcli", "device", "wifi", "connect", ssid, "ifname", "wlan0"], check=False)

def start_access_point():
    """
    Start AP mode using NetworkManager
    """
    # Read AP settings from config
    cfg = load_config()
    ap_cfg = cfg.get("access_point", {}) or {}
    ap_ssid = ap_cfg.get("ssid", "vehicle-datalogger") # Default SSID: vehicle-datalogger
    ap_pass = ap_cfg.get("password", "") # Default password: none

    # Ensure NM is running and interface is free
    subprocess.run(["systemctl", "start", "NetworkManager"])
    subprocess.run(["nmcli", "device", "disconnect", "wlan0"], stdout=subprocess.DEVNULL, stderr=subprocess.DEVNULL)

    # Clean up any previous hotspot profile
    subprocess.run(["nmcli", "connection", "down", AP_CONN_NAME], stdout=subprocess.DEVNULL, stderr=subprocess.DEVNULL)
    subprocess.run(["nmcli", "connection", "delete", AP_CONN_NAME], stdout=subprocess.DEVNULL, stderr=subprocess.DEVNULL)

    # Create the hotspot profile
    subprocess.run([
        "nmcli", "connection", "add",
        "type", "wifi",
        "ifname", "wlan0",
        "con-name", AP_CONN_NAME,
        "autoconnect", "no",
        "ssid", ap_ssid
    ], check=False)

    # Configure AP mode + shared IPv4 (does DHCP/NAT automatically)
    subprocess.run([
        "nmcli", "connection", "modify", AP_CONN_NAME,
        "802-11-wireless.mode", "ap",
        "802-11-wireless.band", "bg",
        "ipv4.method", "shared",
        "ipv6.method", "ignore"
    ], check=False)

    # Security: WPA2-PSK if password present and >= 8 chars; otherwise open
    if ap_pass and len(ap_pass) >= 8:
        subprocess.run([
            "nmcli", "connection", "modify", AP_CONN_NAME,
            "wifi-sec.key-mgmt", "wpa-psk",
            "wifi-sec.psk", ap_pass
        ], check=False)
    else:
        subprocess.run([
            "nmcli", "connection", "modify", AP_CONN_NAME,
            "wifi-sec.key-mgmt", "none"
        ], check=False)

    # Bring the hotspot up
    subprocess.run(["nmcli", "connection", "up", AP_CONN_NAME], check=False)

def stop_access_point():
    """
    Stop AP and ensure NetworkManager is restarted.
    """
    subprocess.run(["nmcli", "connection", "down", AP_CONN_NAME], stdout=subprocess.DEVNULL, stderr=subprocess.DEVNULL)
    subprocess.run(["nmcli", "connection", "delete", AP_CONN_NAME], stdout=subprocess.DEVNULL, stderr=subprocess.DEVNULL)
    subprocess.run(["systemctl", "start", "NetworkManager"])

def main():
    config = load_config()
    trusted_networks = config.get("trusted_networks", [])

    ssids = scan_ssids()
    print(f"Found networks: {ssids}")

    # Try connecting to trusted networks
    for entry in trusted_networks:
        if entry["ssid"] in ssids:
            print(f"Connecting to trusted network: {entry['ssid']}")
            stop_access_point()
            configure_wifi_client(entry["ssid"], entry.get("psk"))
            return

    # If no trusted networks found -> AP mode
    print("No trusted networks found, starting access point")
    start_access_point()

if __name__ == "__main__":
    main()

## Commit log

2025-03-28 CAD data for logger enclosure
    [datalogger_enclosure.step, datalogger_enclosure.stl, datalogger_lid.step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]
2025-03-29 Updated button to reduce wiring
    Also organized gpio setup
2025-03-29 fixing event detection upon multiple script calls
    [datalogger.py]
2025-03-29 Switched to using gpiozero library
2025-03-29 fixed bug with can interface already brought up before script starts
    [datalogger.py]
2025-03-29 bring down can interface upon keyboard interrupt
2025-03-29 Improve button de-bounce
2025-03-29 Fixed auto start and updated README
    [datalogger.py]
2025-05-27 PCB schematic rev 1.0
    [JS202011SCQN.STEP, JS202011SCQN.step, amp_superseal_9-6437287-8.step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]
2025-05-28 Fixed LED turning on at boot
    [datalogger.py]
2025-05-29 Flask webapp for downloading logs
    [can_log_20250528_235653 copy 2.csv, can_log_20250528_235653 copy 3.csv, can_log_20250528_235653 copy 4.csv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]
2025-06-01 Updated CSV output format
    Each column is a separate signal. Multiple devices supported, as column naming is "message_name_signal"
2025-06-11 PCB component placement
    [can_datalogger_board.kicad_pcb, can_datalogger_board.kicad_sch, power_supply.kicad_sch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]
2025-07-19 re-org
    - added docker image of influxDB
    [can_log_20250528_235653 copy 2.csv, can_log_20250528_235653 copy 3.csv, can_log_20250528_235653 copy 4.csv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]
2025-08-08 Refactor datalogging pi service
    1. repo directory structure refactor
    2. creation of a install.sh script for the pi
    3. Improved WiFi service: use trusted networks, or if none exist, start an access point. Makes debugging and testing of new software at home much easier since it connects to a trusted network with in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
    [can_log_20250528_235653 copy 2.csv, can_log_20250528_235653 copy 3.csv, can_log_20250528_235653 copy 4.csv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]
2025-08-08 Fix wifi_manager.py to use NetworkManager
    Also brings up static ip when in AP mode
    [wifi_manager.py]
